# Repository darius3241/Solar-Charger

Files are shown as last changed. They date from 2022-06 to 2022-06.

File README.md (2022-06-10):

A solar powered phone charger

# Description 

This project was created to furfill the class requirments for Power Electionics at Walla Walla University in the Spring of 2022, taught by [Dr. Rob Frohne](https://github.com/frohro). A simple solar powered phone charger intended to charge android smart phone devices was created.  

# Specifications 

The specifications for this charger are: <br/>
• 3W Solar Panel <br/>
• Take between 9 - 12 volts <br/>
• Output current of 333 mA <br/>
• Uses a buck converter <br/>

# Design 

Our design was made using the WEBENCH design tool created by Texas Instruments 



The process was simple. To use this tool we had to specify our just a few parameters which were <br/>

Input supply type (DC) <br/>
• Vin min: 14V <br/>
• Vin max: 25V <br/>

Output <br/>
• Vout: 5V <br/>
• Iout Max: 5A <br/>

Once the parameters were entered, WEBENCH gave us a variety of designs that met are specificiation. 

# Schematic

Below is the selected design we have chosen generated from WEBENCH. It was pick becasue it was one of the only designs that used components that werem't sold out. Due to the world-wide chip shortand many designs had components that were out of stock. Fortunately, we were able to find this design.



# KIcad PCB 

Using Kicad we made a another schematic and PCB to get printed off. Below is the Kicad schematic and PCB 





# Build and Test 

 

# Results 

Below is a photo of a completed design 

B85DE411-732C-41A4-8914-88FEC19A5805_1_105_c
05CC048C-119B-479E-B66E-3C8F0EDC0148_1_105_c

# Experimental Test Results 

Using the power supply we got: <br/>
Output voltage: 5v <br/>
Input current: 460 mA <br/>

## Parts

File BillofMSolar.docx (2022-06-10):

Bill of Materials

Digi-key Cart Share Link (https://www.digikey.com/short/bpnpphhn)

1. Capacitor’s
  a. 220 uF (https://www.digikey.com/en/products/detail/cornell-dubilier-illinois-capacitor/227CKE025MGM/5411712) (QTY: 2)
  b. 100 nF (https://www.digikey.com/en/products/detail/kemet/CDR33BX104AKSS7370/3738766) (QTY: 2)
  c. 10 nF (https://www.digikey.com/en/products/detail/kyocera-avx/CDR31BX103AKUS/3452052) (QTY: 2)
  d. 10 nF (https://www.digikey.com/en/products/detail/kyocera-avx/CDR31BX103AKUS/3452052) (QTY: 2)
  e. 47 uF (https://www.digikey.com/en/products/detail/cornell-dubilier-illinois-capacitor/476CKE035M/5412763) (QTY: 2)
2. Inductor
  a. 68 uH (https://www.digikey.com/en/products/detail/murata-power-solutions-inc/49680SC/5798510) (QTY: 2)
3. USB Connector
  a. USB A (https://www.digikey.com/en/products/detail/molex/0482580002/3044346) (QTY: 2)
4. Simple Switcher Buck Converter
  a. LM267N-5 (https://www.digikey.com/en/products/detail/texas-instruments/LM2672N-5-0-NOPB/363784) (QTY: 2)
5. Connectors (https://www.digikey.com/en/products/detail/adam-tech/EB21A-02-D/9831208)
6. Diodes
  a. Schottky (https://www.digikey.com/en/products/detail/vishay-general-semiconductor-diodes-division/SS2P5-M3-84A/2650623) (QTY: 2)

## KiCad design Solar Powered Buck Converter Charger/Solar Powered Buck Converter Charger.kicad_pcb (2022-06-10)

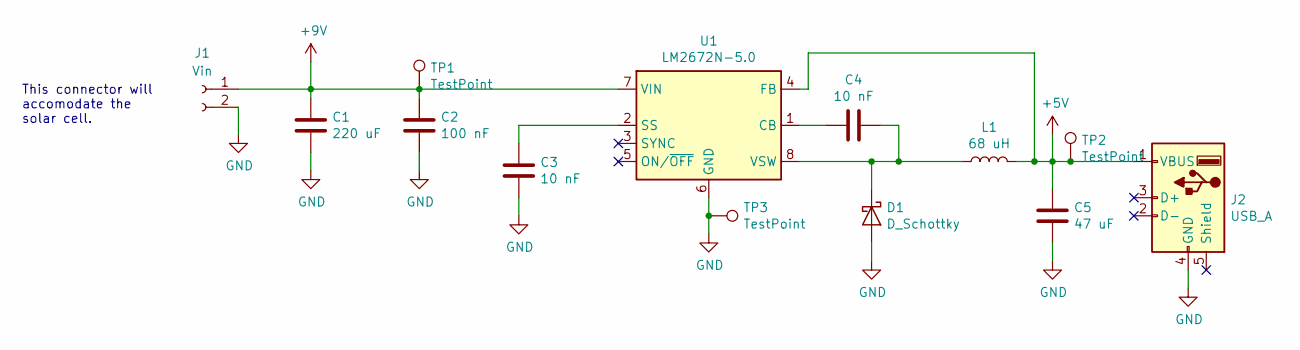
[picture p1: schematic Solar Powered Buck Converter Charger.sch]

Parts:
C1: 220 uF; CP_Radial_D6.3mm_P2.50mm
C2: 100 nF; C_1210
C3, C4: 10 nF; C_0805
C5: 47 uF; CP_Radial_D5.0mm_P2.00mm
D1: D_Schottky; D_Powermite_AK
J1: Vin; TerminalBlock_bornier-2_P5.08mm
J2: USB_A
L1: 68 uH; L_Wuerth_WE-PD-Typ-LS
TP1, TP2, TP3: TestPoint; Pin_Header_Straight_1x01_Pitch2.54mm
U1: LM2672N-5.0; DIP-8_W7.62mm

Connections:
+5V: C5.1, J2.1 (VBUS), L1.2, TP2.1, U1.4 (FB)
+9V: C1.1, C2.1, J1.1, TP1.1, U1.7 (VIN)
GND: C1.2, C2.2, C3.2, C5.2, D1.2 (A), J1.2, J2.4 (GND), TP3.1, U1.6 (GND)
unnamed: C3.1, U1.2 (SS)
unnamed: C4.1, D1.1 (K), L1.1, U1.8 (VSW)
unnamed: C4.2, U1.1 (CB)

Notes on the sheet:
This connector will accomodate the solar cell.

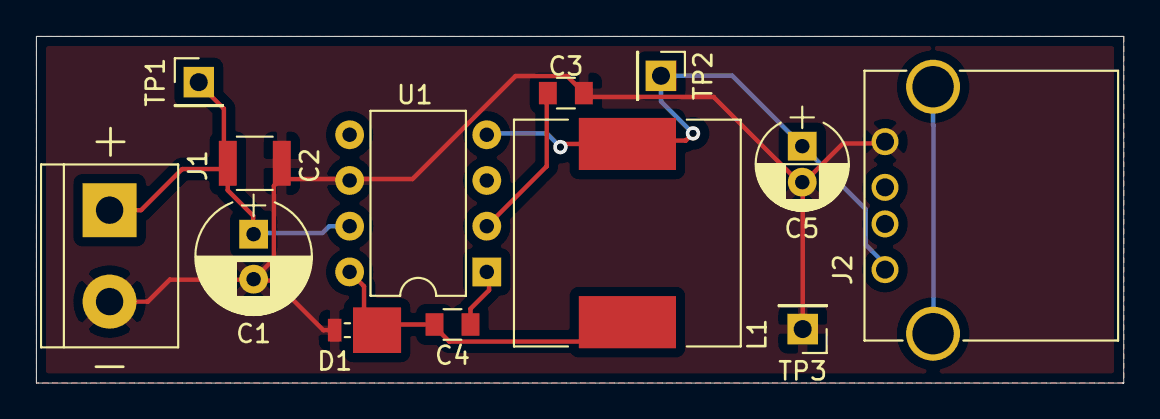
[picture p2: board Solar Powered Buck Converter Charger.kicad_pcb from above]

Board: 2 copper layers, 60.4 x 19.3 mm, 13 parts (0 on the bottom side), 6 nets.
